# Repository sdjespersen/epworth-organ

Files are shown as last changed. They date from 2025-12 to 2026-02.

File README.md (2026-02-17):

# Epworth Organ

Encoders (`primary-encoder` being the primary), decoders (`primary-decoder` being the primary), etc. for the Epworth
organ, targeting the [Raspberry Pi Pico 2](https://datasheets.raspberrypi.com/pico/pico-2-datasheet.pdf), written in
Rust.

## Setup

The best dev setup for this involves using a
[Pico debug probe](https://www.raspberrypi.com/documentation/microcontrollers/debug-probe.html)
and [probe-rs](https://probe.rs). This allows you to get a SWD debugger and UART output, as well as flashing the program
to the chip without holding BOOTSEL while plugging in the USB. (Trust me, it gets old!)

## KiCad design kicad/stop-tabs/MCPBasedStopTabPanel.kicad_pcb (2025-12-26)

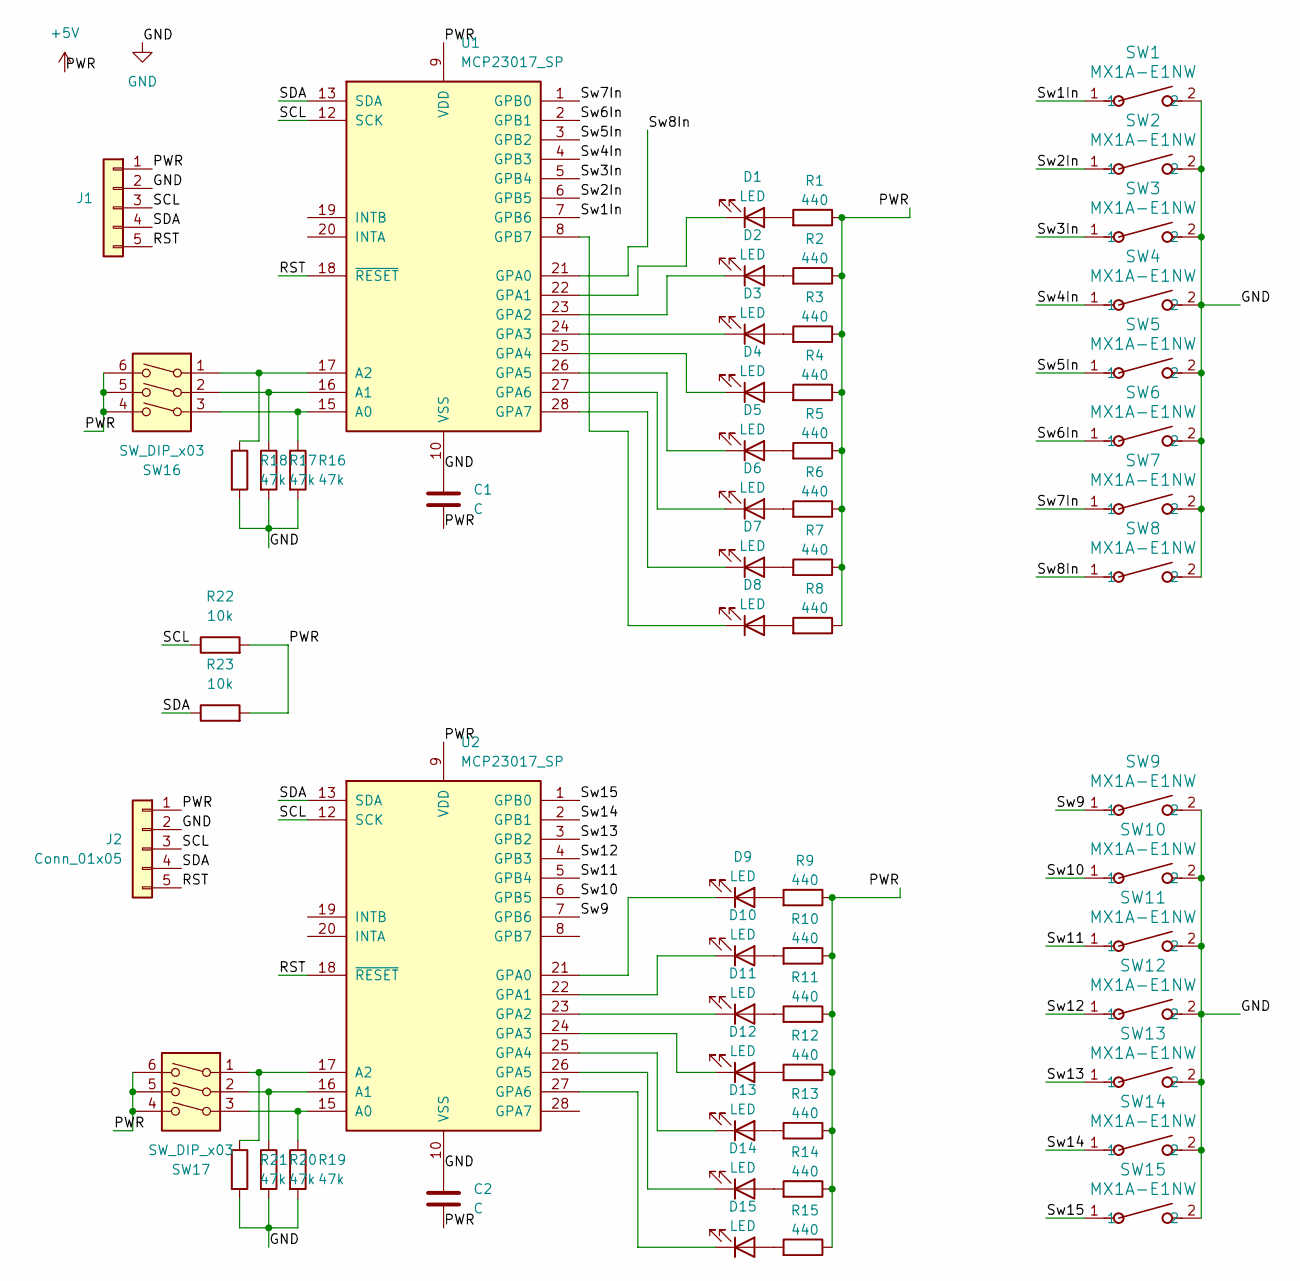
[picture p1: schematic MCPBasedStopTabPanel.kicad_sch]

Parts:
C1, C2: C; CAPRR508W50L508T317H508
D1, D2, D3, D4, D5, D6, D7, D8, D9, D10, D11, D12, D13, D14, D15: LED; LED_D5.0mm
J1, J2: Conn_01x05; JST_XH_B5B-XH-A_1x05_P2.50mm_Vertical
R1, R2, R3, R4, R5, R6, R7, R8, R9, R10, R11, R12, R13, R14, R15: 440; R_Axial_DIN0207_L6.3mm_D2.5mm_P7.62mm_Horizontal
R16, R17, R18, R19, R20, R21: 47k; R_Axial_DIN0207_L6.3mm_D2.5mm_P7.62mm_Horizontal
R22, R23: 10k; R_Axial_DIN0207_L6.3mm_D2.5mm_P7.62mm_Horizontal
SW1, SW2, SW3, SW4, SW5, SW6, SW7, SW8, SW9, SW10, SW11, SW12, SW13, SW14, SW15: MX1A-E1NW; SW_Cherry_MX_1.00u_PCB
SW16, SW17: SW_DIP_x03; SW_DIP_SPSTx03_Slide_9.78x9.8mm_W7.62mm_P2.54mm
U1, U2: MCP23017_SP; DIP-28_W7.62mm

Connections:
+5V: C1.2, C2.2, J1.1, J2.1, R1.1, R2.1, R3.1, R4.1, R5.1, R6.1, R7.1, R8.1, R9.1, R10.1, R11.1, R12.1, R13.1, R14.1, R15.1, R22.2, R23.2, SW16.4, SW16.5, SW16.6, SW17.4, SW17.5, SW17.6, U1.9 (VDD), U2.9 (VDD)
/RST: J1.5, J2.5, U1.18 (~RESET), U2.18 (~RESET)
/SCL: J1.3, J2.3, R22.1, U1.12 (SCK), U2.12 (SCK)
/SDA: J1.4, J2.4, R23.1, U1.13 (SDA), U2.13 (SDA)
/Sw1In: SW1.1, U1.7 (GPB6)
/Sw2In: SW2.1, U1.6 (GPB5)
/Sw3In: SW3.1, U1.5 (GPB4)
/Sw4In: SW4.1, U1.4 (GPB3)
/Sw5In: SW5.1, U1.3 (GPB2)
/Sw6In: SW6.1, U1.2 (GPB1)
/Sw7In: SW7.1, U1.1 (GPB0)
/Sw8In: SW8.1, U1.21 (GPA0)
/Sw9: SW9.1, U2.7 (GPB6)
/Sw10: SW10.1, U2.6 (GPB5)
/Sw11: SW11.1, U2.5 (GPB4)
/Sw12: SW12.1, U2.4 (GPB3)
/Sw13: SW13.1, U2.3 (GPB2)
/Sw14: SW14.1, U2.2 (GPB1)
/Sw15: SW15.1, U2.1 (GPB0)
GND: C1.1, C2.1, J1.2, J2.2, R16.2, R17.2, R18.2, R19.2, R20.2, R21.2, SW1.2, SW2.2, SW3.2, SW4.2, SW5.2, SW6.2, SW7.2, SW8.2, SW9.2, SW10.2, SW11.2, SW12.2, SW13.2, SW14.2, SW15.2, U1.10 (VSS), U2.10 (VSS)
unnamed: D1.2 (A), R1.2
unnamed: D1.1 (K), U1.22 (GPA1)
unnamed: D2.2 (A), R2.2
unnamed: D2.1 (K), U1.23 (GPA2)
unnamed: D3.2 (A), R3.2
unnamed: D3.1 (K), U1.24 (GPA3)
unnamed: D4.2 (A), R4.2
unnamed: D4.1 (K), U1.25 (GPA4)
unnamed: D5.2 (A), R5.2
unnamed: D5.1 (K), U1.26 (GPA5)
unnamed: D6.2 (A), R6.2
unnamed: D6.1 (K), U1.27 (GPA6)
unnamed: D7.2 (A), R7.2
unnamed: D7.1 (K), U1.28 (GPA7)
unnamed: D8.2 (A), R8.2
unnamed: D8.1 (K), U1.8 (GPB7)
unnamed: D9.2 (A), R9.2
unnamed: D9.1 (K), U2.21 (GPA0)
unnamed: D10.2 (A), R10.2
unnamed: D10.1 (K), U2.22 (GPA1)
unnamed: D11.2 (A), R11.2
unnamed: D11.1 (K), U2.23 (GPA2)
unnamed: D12.2 (A), R12.2
unnamed: D12.1 (K), U2.24 (GPA3)
unnamed: D13.2 (A), R13.2
unnamed: D13.1 (K), U2.25 (GPA4)
unnamed: D14.2 (A), R14.2
unnamed: D14.1 (K), U2.26 (GPA5)
unnamed: D15.2 (A), R15.2
unnamed: D15.1 (K), U2.27 (GPA6)
unnamed: R16.1, SW16.3, U1.15 (A0)
unnamed: R17.1, SW16.2, U1.16 (A1)
unnamed: R18.1, SW16.1, U1.17 (A2)
unnamed: R19.1, SW17.3, U2.15 (A0)
unnamed: R20.1, SW17.2, U2.16 (A1)
unnamed: R21.1, SW17.1, U2.17 (A2)

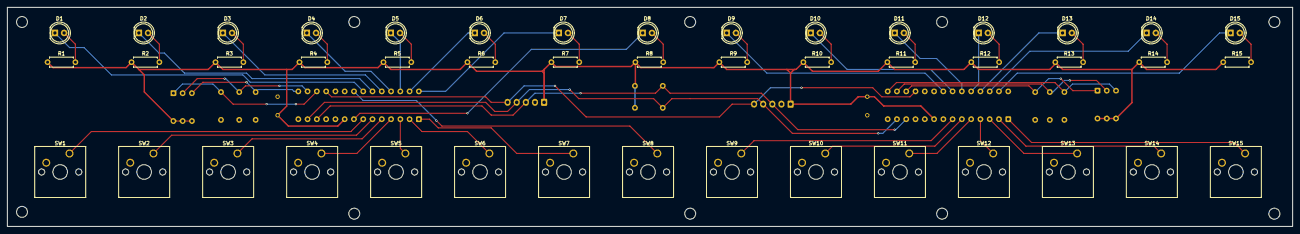
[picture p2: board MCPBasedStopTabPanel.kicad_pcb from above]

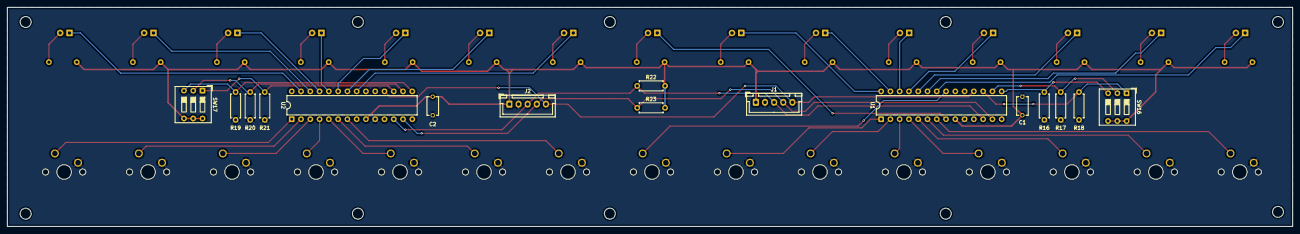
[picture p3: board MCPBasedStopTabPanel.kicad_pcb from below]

Board: 2 copper layers, 352.0 x 60.0 mm, 61 parts (16 on the bottom side), 56 nets.

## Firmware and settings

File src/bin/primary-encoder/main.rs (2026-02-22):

#![no_std]
#![no_main]

mod mcp23017;
mod presets;
mod usb_midi;

use panic_probe as _;

use core::cell::RefCell;

use embassy_embedded_hal::shared_bus::blocking::i2c::I2cDevice;
use embassy_executor::Spawner;
use embassy_rp::flash::Flash;
use embassy_rp::gpio::{AnyPin, Level, Output};
use embassy_rp::peripherals::{I2C0, SPI0, UART0, USB};
use embassy_rp::spi;
use embassy_rp::{Peri, bind_interrupts, i2c, uart, usb as rp_usb};
use embassy_sync::blocking_mutex::Mutex;
use embassy_sync::blocking_mutex::raw::CriticalSectionRawMutex;
use embassy_sync::channel::Channel;
use embassy_sync::signal::Signal;
use embassy_time::Timer;
use embassy_usb::class::midi as eusb_midi;
use embassy_usb::class::midi::MidiClass;
use embassy_usb::{Builder as UsbBuilder, Config as UsbConfig};
use embedded_io_async::Write;
use epworth_organ::Division;
use epworth_organ::command::{Command, CommandSource};
use epworth_organ::debouncer::Debouncer;
use epworth_organ::encoder::Encoder;
use epworth_organ::event::Event;
use epworth_organ::stops::{Stop, offset_to_div};
use epworth_organ::uart::UartReader;
use postcard::to_slice_cobs;
use static_cell::{ConstStaticCell, StaticCell};

use crate::mcp23017::MCP23017;
use crate::mcp23017::Port;
use crate::presets::Presets;
use crate::usb_midi::{receive_command_from_usb, write_event_to_usb};

type I2c0Bus = Mutex<CriticalSectionRawMutex, RefCell<i2c::I2c<'static, I2C0, i2c::Blocking>>>;
type I2c0Mcp =
    MCP23017<I2cDevice<'static, CriticalSectionRawMutex, i2c::I2c<'static, I2C0, i2c::Blocking>>>;

bind_interrupts!(struct Irqs {
    USBCTRL_IRQ => rp_usb::InterruptHandler<USB>;
    UART0_IRQ => uart::BufferedInterruptHandler<UART0>;
});

// These two indices have to be determined when everything is hooked up.
const SAVE_PISTON_IDX: u8 = 7;
const GENERAL_CANCEL_PISTON_IDX: u8 = 6;
const MCP_I2C_ADDRESSES: [[u8; 2]; 4] = [[0x20, 0x21], [0x22, 0x23], [0x24, 0x25], [0x26, 0x27]];
const DIVISIONS: [Division; 4] = [
    Division::Swell,
    Division::Great,
    Division::Choir,
    Division::Pedal,
];

// This stop state representation is LSB first, i.e. looking at the stop tab panels from the front, LSB is on the left.
// Furthermore, the 16 bits corresponding to the swell division are in the 16 lowest bits, the next 16 are the great,
// followed by the choir division and finally the pedal division. The MSB for each division is always 0, as it is not
// connected to any physical hardware. (No division has more than 15 stops.)
static STOP_STATE: Signal<CriticalSectionRawMutex, u64> = Signal::new();
static PRESET_STORE: StaticCell<Presets> = StaticCell::new();

// Queue for all commands on the organ. These commands can be either generated by mechanical interactions with the
// console (e.g. pressing a stop tab button, moving an expression pedal, etc.), including mechanical interactions
// relayed to this particular MCU over UART, or they can be received over USB MIDI.
static COMMANDS: Channel<CriticalSectionRawMutex, (Command, CommandSource), 8> = Channel::new();

// Queues for events destined for the decoders (via UART) or the computer (via USB).
static UART_EVENTS: Channel<CriticalSectionRawMutex, Event, 8> = Channel::new();
static USB_EVENTS: Channel<CriticalSectionRawMutex, Event, 8> = Channel::new();

static USB_CONFIG_DESCRIPTOR: ConstStaticCell<[u8; 512]> = ConstStaticCell::new([0; 512]);
static USB_BOS_DESCRIPTOR: ConstStaticCell<[u8; 256]> = ConstStaticCell::new([0; 256]);
static USB_CONTROL_BUF: ConstStaticCell<[u8; 128]> = ConstStaticCell::new([0; 128]);

fn get_mcps(i2c_bus: &'static I2c0Bus) -> [[I2c0Mcp; 2]; 4] {
    MCP_I2C_ADDRESSES.map(|[addr0, addr1]| {
        [
            MCP23017::new(I2cDevice::new(i2c_bus), addr0),
            MCP23017::new(I2cDevice::new(i2c_bus), addr1),
        ]
    })
}

#[embassy_executor::task]
async fn write_stop_state_to_leds(i2c_bus: &'static I2c0Bus) {
    let mcp_pairs = &mut get_mcps(i2c_bus);

    loop {
        let mut stop_state: u64 = STOP_STATE.wait().await;

        // This is our approach to batching lots of little changes: Wait for a brief interval before reading the stop
        // states again.
        Timer::after_millis(1).await;

        stop_state = STOP_STATE.try_take().unwrap_or(stop_state);

        for (mcp_pair, div) in mcp_pairs.iter_mut().zip(DIVISIONS) {
            // Remember, stop state is LSB first.
            let state = stop_state >> (16 * div as u8) & 0xFFFF;
            let left_half = !(state & 0xFF) as u8;
            let right_half = !(state >> 8) as u8;
            mcp_pair[0]
                .write_gpio(Port::GPIOA, (left_half & 0x7F) << 1)
                .unwrap();
            mcp_pair[0]
                .write_gpio(Port::GPIOB, left_half & 0x80)
                .unwrap();
            mcp_pair[1]
                .write_gpio(Port::GPIOA, right_half & 0x7F)
                .unwrap();
        }
    }
}

#[embassy_executor::task]
async fn scan_stop_tab_buttons(i2c_bus: &'static I2c0Bus) {
    let mut mcp_pairs = get_mcps(i2c_bus);
    let mut stop_tab_button_debouncer: Debouncer<5> = Debouncer::<5>::new(!0u64);

    loop {
        let mut raw_reading = 0u64;
        for (j, mcp_pair) in mcp_pairs.iter_mut().enumerate() {
            // These readings are L-to-R looking at the front of the stop tab panels, aka MSB first.
            let mut raw_div_reading = 0x01u16; // LSB always 1, not hooked up
            raw_div_reading |= ((mcp_pair[0].read_gpio(Port::GPIOA).unwrap() & 0x01) as u16) << 8;
            raw_div_reading |= ((mcp_pair[0].read_gpio(Port::GPIOB).unwrap() & 0x7F) as u16) << 9;
            raw_div_reading |= ((mcp_pair[1].read_gpio(Port::GPIOB).unwrap() & 0x7F) as u16) << 1;
            raw_reading |= (raw_div_reading as u64) << (16 * j);
        }
        stop_tab_button_debouncer.update(raw_reading);
        for i in stop_tab_button_debouncer.falling_edges() {
            // Because the raw readings (and hence debouncers) are MSB first, need to invert the stop number.
            if let Some(stop) = Stop::try_from(offset_to_div(i), 15 - (i % 16)) {
                COMMANDS
                    .send((Command::StopToggle(stop), CommandSource::Local))
                    .await;
            }
        }
        Timer::after_micros(500).await;
    }
}

#[embassy_executor::task]
async fn scan_pistons(
    mut spi: spi::Spi<'static, SPI0, spi::Async>,
    load_pin: Peri<'static, AnyPin>,
) {
    let mut piston_debouncer = Debouncer::<5>::new(!0u64);

    let mut piston_load_pin = Output::new(load_pin, Level::Low);

    loop {
        // Load piston states into 74HC165 shift registers
        piston_load_pin.set_low();
        piston_load_pin.set_high();

        let mut rx_buf = [0u8; 4];
        let _ = spi.read(&mut rx_buf).await;

        let raw_piston_reading = rx_buf[0] as u64
            | ((rx_buf[1] as u64) << 8)
            | ((rx_buf[2] as u64) << 16)
            | ((rx_buf[3] as u64) << 24);

        piston_debouncer.update(raw_piston_reading);

        for i in piston_debouncer.falling_edges() {
            if i == SAVE_PISTON_IDX {
                COMMANDS
                    .send((Command::EnableSave(true), CommandSource::Local))
                    .await;
            } else if i == GENERAL_CANCEL_PISTON_IDX {
                COMMANDS
                    .send((Command::GeneralCancel(), CommandSource::Local))
                    .await;
            } else {
                COMMANDS
                    .send((Command::RecallPreset(i), CommandSource::Local))
                    .await;
            }
        }

        for i in piston_debouncer.rising_edges() {
            if i == SAVE_PISTON_IDX {
                COMMANDS
                    .send((Command::EnableSave(false), CommandSource::Local))
                    .await;
            }
        }

        Timer::after_micros(500).await;
    }
}

#[embassy_executor::task]
async fn usb_midi_writer(
    mut usb_midi_tx: eusb_midi::Sender<'static, rp_usb::Driver<'static, USB>>,
) {
    // TODO: Handle the case where the USB cable gets connected/disconnected while the program is running.
    // We can probably implement this by breaking out of the inner loop if we time out when writing packets.
    usb_midi_tx.wait_connection().await;

    loop {
        let event = USB_EVENTS.receive().await;
        write_event_to_usb(event, &mut usb_midi_tx).await;
    }
}

#[embassy_executor::task]
async fn usb_midi_reader(
    mut usb_midi_rx: eusb_midi::Receiver<'static, rp_usb::Driver<'static, USB>>,
) {
    // TODO: Handle the case where the USB cable gets connected/disconnected while the program is running.
    usb_midi_rx.wait_connection().await;

    let mut data = [0u8; 64];

    loop {
        receive_command_from_usb(&mut data, &mut usb_midi_rx, async |cmd| {
            COMMANDS.send((cmd, CommandSource::External)).await;
        })
        .await;
    }
}

#[embassy_executor::task]
async fn usb_midi(spawner: Spawner, usb: Peri<'static, USB>) {
    let driver = rp_usb::Driver::new(usb, Irqs);
    let mut config = UsbConfig::new(0xc0de, 0xcafe);
    config.manufacturer = Some("RP Pico 2");
    config.product = Some("Epworth Organ MIDI");
    config.serial_number = Some("12345678");
    config.max_power = 100;
    config.max_packet_size_0 = 64;

    let mut builder = UsbBuilder::new(
        driver,
        config,
        USB_CONFIG_DESCRIPTOR.take(),
        USB_BOS_DESCRIPTOR.take(),
        &mut [], // no msos descriptors
        USB_CONTROL_BUF.take(),
    );

    let midi_class = MidiClass::new(&mut builder, 1, 1, 64);

    // Build the builder.
    let mut usb_device = builder.build();

    let (usb_midi_tx, usb_midi_rx) = midi_class.split();

    spawner.spawn(usb_midi_writer(usb_midi_tx)).unwrap();
    spawner.spawn(usb_midi_reader(usb_midi_rx)).unwrap();

    // Run the USB device forever.
    loop {
        usb_device.run().await;
    }
}

#[embassy_executor::task]
async fn uart_reader(uart_rx: uart::BufferedUartRx) {
    let mut uart_rdr = UartReader::new(uart_rx);

    loop {
        uart_rdr
            .feed::<Command>(async |data| {
                COMMANDS.send((data, CommandSource::Local)).await;
            })
            .await;
    }
}

#[embassy_executor::task]
async fn uart_writer(mut uart_tx: uart::BufferedUartTx) {
    loop {
        let event = UART_EVENTS.receive().await;
        // We have to be careful here about buffer size! Preset recall serializes to 12 bytes in my testing. I'm
        // leaving a few extra just in case i introduce anything around that size.
        let mut buf = [0u8; 16];
        let written = to_slice_cobs(&event, &mut buf).unwrap();
        let _ = uart_tx.write_all(written).await;
    }
}

fn setup_mcps(i2c_bus: &'static I2c0Bus) {
    for mcp_pair in get_mcps(i2c_bus).iter_mut() {
        mcp_pair[0].init_hardware().unwrap();
        mcp_pair[1].init_hardware().unwrap();
        // Set pin modes (input/output) for MCP23017s based on the schematic
        mcp_pair[0].port_mode(Port::GPIOA, 0x01).unwrap();
        mcp_pair[0].port_mode(Port::GPIOB, 0x7F).unwrap();
        mcp_pair[1].port_mode(Port::GPIOA, 0x00).unwrap();
        mcp_pair[1].port_mode(Port::GPIOB, 0x7F).unwrap();
        // Write all outputs high, inputs low.
        mcp_pair[0].write_gpio(Port::GPIOA, 0xFE).unwrap();
        mcp_pair[0].write_gpio(Port::GPIOB, 0x80).unwrap();
        mcp_pair[1].write_gpio(Port::GPIOA, 0x7F).unwrap();
        mcp_pair[1].write_gpio(Port::GPIOB, 0x00).unwrap();
    }
}

#[embassy_executor::task]
async fn main_event_handler(preset_store: &'static mut Presets<'static>) {
    // let mut stop_state: u64 = 0u64;
    // let mut awaiting_save = false;
    let mut encoder = Encoder::new(preset_store);

    // Flush initial stop state.
    STOP_STATE.signal(encoder.get_stop_state());

    loop {
        let (command, src) = COMMANDS.receive().await;

        let command_result = encoder.handle(command).await;

        if command_result.1 {
            STOP_STATE.signal(encoder.get_stop_state())
        }

        if let Some(e) = command_result.0 {
            if let CommandSource::Local = src {
                let _ = USB_EVENTS.try_send(e);
            }
            UART_EVENTS.send(e).await;
        }
    }
}

#[embassy_executor::main]
async fn main(spawner: Spawner) {
    let p = embassy_rp::init(Default::default());

    let i2c = embassy_rp::i2c::I2c::new_blocking(p.I2C0, p.PIN_5, p.PIN_4, i2c::Config::default());
    static I2C_BUS: StaticCell<I2c0Bus> = StaticCell::new();
    let i2c_bus = I2C_BUS.init(Mutex::new(i2c.into()));

    let spi = spi::Spi::new_rxonly(
        p.SPI0,
        p.PIN_18,
        p.PIN_16,
        p.DMA_CH1,
        p.DMA_CH2,
        spi::Config::default(),
    );
    spawner.spawn(scan_pistons(spi, p.PIN_17.into())).unwrap();

    spawner
        .spawn(main_event_handler(
            PRESET_STORE.init(Presets::new(Flash::new(p.FLASH, p.DMA_CH0))),
        ))
        .unwrap();

    static TX_BUF: StaticCell<[u8; 16]> = StaticCell::new();
    let tx_buf = &mut TX_BUF.init([0; 16])[..];
    static RX_BUF: StaticCell<[u8; 16]> = StaticCell::new();
    let rx_buf = &mut RX_BUF.init([0; 16])[..];
    let uart_txrx = uart::BufferedUart::new(
        p.UART0,
        p.PIN_0,
        p.PIN_1,
        Irqs,
        tx_buf,
        rx_buf,
        uart::Config::default(),
    );
    let (uart_tx, uart_rx) = uart_txrx.split();
    spawner.spawn(uart_reader(uart_rx)).unwrap();
    spawner.spawn(uart_writer(uart_tx)).unwrap();

    setup_mcps(i2c_bus);
    spawner.spawn(scan_stop_tab_buttons(i2c_bus)).unwrap();
    spawner.spawn(write_stop_state_to_leds(i2c_bus)).unwrap();
    spawner.spawn(usb_midi(spawner, p.USB)).unwrap();

    defmt::info!("All tasks spawned.");

    // Heartbeat task comes last, and happens on the main loop, roughly indicating that all tasks spawned successfully.
    let mut led = Output::new(p.PIN_25, Level::Low);

    loop {
        led.toggle();
        Timer::after_secs(1).await;
    }
}

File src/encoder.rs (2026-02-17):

use crate::{command::Command, event::Event};

pub trait PresetStore {
    fn save(&mut self, key: u8, value: u64) -> impl Future<Output = ()>;
    fn load(&mut self, key: u8) -> impl Future<Output = u64>;
}

pub struct Encoder<'d, T: PresetStore> {
    stops: u64,
    awaiting_save: bool,
    preset_store: &'d mut T,
}

pub struct CommandResult(pub Option<Event>, pub bool);

impl<'d, T: PresetStore> Encoder<'d, T> {
    pub fn new(preset_store: &'d mut T) -> Self {
        Self {
            stops: 0u64,
            awaiting_save: false,
            preset_store: preset_store,
        }
    }

    pub fn get_stop_state(&self) -> u64 {
        self.stops
    }

    // This is the guts of the primary encoder MCU. All commands issued to the organ go through this handler in order
    // to affect any state on the organ. Some commands pass through essentially untouched to the decoder, while others
    // may be "absorbed" by the encoder and result in zero outbound events (e.g. "save preset"). This handler applies
    // state-related logic to incoming encoder commands (e.g. "toggle" messages converted to "on" or "off" depending on
    // state), but it does not concern itself with couplings; those will be handled by the decoder.
    pub async fn handle(&mut self, cmd: Command) -> CommandResult {
        match cmd {
            Command::NoteOff(div, value) => CommandResult(Some(Event::NoteOff(div, value)), false),
            Command::NoteOn(div, value) => CommandResult(Some(Event::NoteOn(div, value)), false),
            Command::StopOff(stop) => {
                self.stops &= !(1 << stop.offset());
                CommandResult(Some(Event::StopOff(stop)), true)
            }
            Command::StopOn(stop) => {
                self.stops |= 1 << stop.offset();
                CommandResult(Some(Event::StopOn(stop)), true)
            }
            Command::StopToggle(stop) => {
                let mask = 1 << stop.offset();
                self.stops ^= mask;
                if self.stops & mask != 0 {
                    CommandResult(Some(Event::StopOn(stop)), true)
                } else {
                    CommandResult(Some(Event::StopOff(stop)), true)
                }
            }
            Command::GeneralCancel() => {
                self.stops = 0;
                CommandResult(Some(Event::GeneralCancel()), true)
            }
            Command::RecallPreset(idx) => {
                if self.awaiting_save {
                    // Saving a preset is internal; it emits no events.
                    self.preset_store.save(idx, self.stops).await;
                    // Safety: Disengage save mode if we've already written a preset.
                    self.awaiting_save = false;
                    CommandResult(None, false)
                } else {
                    self.stops = self.preset_store.load(idx).await;
                    CommandResult(Some(Event::PresetRecalled(idx, self.stops)), true)
                }
            }
            Command::EnableSave(val) => {
                self.awaiting_save = val;
                CommandResult(None, false)
            }
            Command::Expression(div, value) => {
                CommandResult(Some(Event::Expression(div, value)), false)
            }
            Command::Crescendo(value) => CommandResult(Some(Event::Crescendo(value)), false),
        }
    }
}

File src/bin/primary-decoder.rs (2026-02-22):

#![no_std]
#![no_main]

use embassy_sync::signal::Signal;
use panic_probe as _;

use embassy_executor::Spawner;
use embassy_rp::gpio::{AnyPin, Level, Output};
use embassy_rp::peripherals::{SPI0, UART0};
use embassy_rp::spi;
use embassy_rp::{Peri, bind_interrupts, uart};
use embassy_sync::blocking_mutex::raw::CriticalSectionRawMutex;
use embassy_sync::channel::Channel;
use embassy_time::Timer;
use epworth_organ::decoder::Decoder;
use epworth_organ::event::Event;
use epworth_organ::uart::UartReader;
use static_cell::StaticCell;

bind_interrupts!(struct Irqs {
    UART0_IRQ => uart::BufferedInterruptHandler<UART0>;
});

const B: [u32; 4] = [0x55555555, 0x33333333, 0x0F0F0F0F, 0x00FF00FF];
const S: [u32; 4] = [1, 2, 4, 8];
const NIBBLE_REVERSE_LOOKUP: [u8; 16] = [
    0x0, 0x8, 0x4, 0xc, 0x2, 0xa, 0x6, 0xe, 0x1, 0x9, 0x5, 0xd, 0x3, 0xb, 0x7, 0xf,
];

// Queue for all events on the decoder. The only way events make it onto the decoder is over UART.
static EVENTS: Channel<CriticalSectionRawMutex, Event, 8> = Channel::new();
static STOP_STATE: Signal<CriticalSectionRawMutex, u64> = Signal::new();

fn interleave_bits(mut x: u32, mut y: u32) -> u32 {
    for i in (0..4).rev() {
        x = (x | (x << S[i])) & B[i];
        y = (y | (y << S[i])) & B[i];
    }
    x | (y << 1)
}

#[embassy_executor::task]
async fn write_stop_state(
    mut spi: spi::Spi<'static, SPI0, spi::Async>,
    latch_pin: Peri<'static, AnyPin>,
) {
    let mut stops_latch_pin = Output::new(latch_pin, Level::Low);

    loop {
        let mut stop_state: u64 = STOP_STATE.wait().await;

        // This is our approach to batching lots of little changes: Wait for a brief interval before reading the stop
        // states again.
        Timer::after_millis(1).await;

        stop_state = STOP_STATE.try_take().unwrap_or(stop_state);

        // There's a lot going on the in the next few paragraphs.
        //
        // First off, the stop state saved in this program is ordered logically in terms of manuals: swell, great,
        // choir, and finally pedal. However, the way the stops are electrically wired in the combination action box is
        // completely different. From organist's left to right, it goes swell, pedal, swell, pedal, ... until the swell
        // and pedal stops are exhausted, and then it picks up with great, choir, great, choir, etc. This means that
        // we need to "interleave" the bits of the swell stop state with the bits of the pedal stop state, and same for
        // the great and the choir.
        //
        // Second, the wiring of the outputs on the MIC5891YN line drivers necessitates a further reshuffling. Because
        // of the pinout on the chip, we need to remap the bit positions in each byte as follows:
        // 0 -> 4, 1 -> 5, 2 -> 6, 3 -> 7, 4 -> 3, 5 -> 2, 6 -> 1, 7 -> 0
        // Reversing the high nibble and then swapping high and low nibbles accomplishes this.
        let left_half = interleave_bits(
            (stop_state >> 16 & 0xFFFF) as u32,
            (stop_state >> 32 & 0xFFFF) as u32,
        );
        let right_half = interleave_bits(
            (stop_state >> 48 & 0xFFFF) as u32,
            (stop_state & 0xFFFF) as u32,
        );

        let mut buf: [u8; 8] = ((left_half as u64) << 32 | (right_half as u64)).to_le_bytes();
        for i in 0..buf.len() {
            // Reverse high nibble, then swap nibbles
            buf[i] =
                ((buf[i] & 0x0F) << 4) | NIBBLE_REVERSE_LOOKUP[((buf[i] & 0xF0) >> 4) as usize];
        }
        let _ = spi.write(&buf).await;

        stops_latch_pin.set_high();
        stops_latch_pin.set_low();
    }
}

#[embassy_executor::task]
async fn uart_reader(uart_rx: uart::BufferedUartRx) {
    let mut uart_rdr = UartReader::new(uart_rx);

    loop {
        uart_rdr
            .feed::<Event>(async |event| {
                EVENTS.send(event).await;
            })
            .await;
    }
}

#[embassy_executor::task]
async fn main_event_handler() {
    let mut decoder = Decoder::new();

    // Signal the initial stop state.
    STOP_STATE.signal(decoder.stop_state());

    loop {
        let event = EVENTS.receive().await;
        let result = decoder.handle(event);
        if let Some(stop_state) = result.stop_state {
            STOP_STATE.signal(stop_state);
        }
    }
}

#[embassy_executor::main]
async fn main(spawner: Spawner) {
    let p = embassy_rp::init(Default::default());

    // Disable stops output until writer task is ready.
    let mut stops_oe_pin = Output::new(p.PIN_21, Level::High);

    spawner.spawn(main_event_handler()).unwrap();

    static TX_BUF: StaticCell<[u8; 16]> = StaticCell::new();
    let tx_buf = &mut TX_BUF.init([0; 16])[..];
    static RX_BUF: StaticCell<[u8; 16]> = StaticCell::new();
    let rx_buf = &mut RX_BUF.init([0; 16])[..];
    let uart_txrx = uart::BufferedUart::new(
        p.UART0,
        p.PIN_0,
        p.PIN_1,
        Irqs,
        tx_buf,
        rx_buf,
        uart::Config::default(),
    );
    let (_uart_tx, uart_rx) = uart_txrx.split();
    spawner.spawn(uart_reader(uart_rx)).unwrap();
    // spawner.spawn(uart_writer(uart_tx)).unwrap();

    let spi = spi::Spi::new_txonly(
        p.SPI0,
        p.PIN_18,
        p.PIN_19,
        p.DMA_CH0,
        spi::Config::default(),
    );
    spawner
        .spawn(write_stop_state(spi, p.PIN_20.into()))
        .unwrap();
    // Enable stops output now that the writer task is ready.
    stops_oe_pin.set_low();

    // Heartbeat task comes last, and happens on the main loop, roughly indicating that all tasks spawned successfully.
    let mut led = Output::new(p.PIN_25, Level::Low);

    loop {
        led.toggle();
        Timer::after_secs(1).await;
    }
}

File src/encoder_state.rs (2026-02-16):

use crate::presets::PresetStore;
use crate::{command::Command, event::Event};

pub struct EncoderState<'d> {
    stop_state: u64,
    awaiting_save: bool,
    preset_store: &'d mut PresetStore<'d>,
}

pub struct CommandResult(pub Option<Event>, pub bool);

impl<'d> EncoderState<'d> {
    pub fn new(preset_store: &'d mut PresetStore<'d>) -> Self {
        Self {
            stop_state: 0u64,
            awaiting_save: false,
            preset_store: preset_store,
        }
    }

    pub fn get_stop_state(&self) -> u64 {
        self.stop_state
    }

    pub async fn command(&mut self, cmd: Command) -> CommandResult {
        // This is the guts of the primary encoder MCU. All commands issued to the organ go through this event loop in
        // order to affect any state on the organ. Some commands pass through essentially untouched to the decoder,
        // while others may result in numerous or even zero outbound events. This first match applies state-related
        // logic to incoming encoder commands (e.g. "toggle" messages converted to "on" or "off" depending on state).
        match cmd {
            Command::NoteOff(div, value) => CommandResult(Some(Event::NoteOff(div, value)), false),
            Command::NoteOn(div, value) => CommandResult(Some(Event::NoteOn(div, value)), false),
            Command::StopOff(div, idx) => {
                self.stop_state &= !(1 << 16 * div as u8 + idx);
                CommandResult(Some(Event::StopOff(div, idx)), true)
            }
            Command::StopOn(div, idx) => {
                self.stop_state |= 1 << 16 * div as u8 + idx;
                CommandResult(Some(Event::StopOn(div, idx)), true)
            }
            Command::StopToggle(div, idx) => {
                let shift = 16 * div as u8 + idx;
                self.stop_state ^= 1 << shift;
                if self.stop_state >> shift & 1 == 1 {
                    CommandResult(Some(Event::StopOn(div, idx)), true)
                } else {
                    CommandResult(Some(Event::StopOff(div, idx)), true)
                }
            }
            Command::GeneralCancel() => {
                self.stop_state = 0;
                CommandResult(Some(Event::GeneralCancel()), true)
            }
            Command::RecallPreset(idx) => {
                if self.awaiting_save {
                    // Saving a preset is internal; it emits no events.
                    self.preset_store.save(idx, &self.stop_state).await;
                    // Safety: Disengage save mode if we've already written one preset.
                    self.awaiting_save = false;
                    CommandResult(None, false)
                } else {
                    self.stop_state = self.preset_store.load(idx).await;
                    CommandResult(Some(Event::PresetRecalled(idx, self.stop_state)), true)
                }
            }
            Command::EnableSave(val) => {
                self.awaiting_save = val;
                CommandResult(None, false)
            }
            Command::Expression(div, value) => {
                CommandResult(Some(Event::Expression(div, value)), false)
            }
            Command::Crescendo(value) => CommandResult(Some(Event::Crescendo(value)), false),
        }
    }
}

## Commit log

2025-12-15 Fake encoder for testing
2025-12-24 Draft of stop tab buttons
2025-12-26 Add KiCad project/schematic/PCB design for stop tab panel.
    [MCPBasedStopTabPanel.kicad_pcb, MCPBasedStopTabPanel.kicad_sch]
2026-01-01 Button presses are detectable now!
2026-01-01 Ignore some KiCad artifacts
2026-01-02 Encoder and decoder working on Teensy!
    Tested it out, and the Teensys talk to each other just fine over a
    single line ("unidirectional UART"?). I tried to get this working
    with an Arduino Nano Every playing the role of encoder, but had
    trouble transmitting MIDI data properly.
2026-01-02 Encoder code works on Arduino Nano Every!
2026-01-02 Pistons functional!
2026-01-07 Fix bug with LED D9.
2026-01-14 Encoder is now in Rust.
2026-01-14 Aaaand decoder ported to Rust, too.
    There was a small bugfix in the encoder.
    [main.rs]
2026-01-14 Add heartbeat LED and small loop delay.
2026-02-12 Feature/rp2350 (#1)
    * First draft of RP2350. Going well!
    Uses Embassy, async, all the bells and whistles.
    * Make heartbeat the "main" task
    * Add lil note about stop state flushing
    * Batch LED changes
    * Add first bits of USB MIDI functionality.
    CC only for now.
    I think i have an issue during preset recall: In fact, i should emit
    all corresponding MIDI CCs, but right now it does not do that.
    * Set a timeout on USB writes.
    This solves the issue wherein we block forever because nobody is
    "listening" on the USB port.
    * Make usb config-related static cells `ConstStaticCell`.
    * Preset recall now emits MIDI CCs.
    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
    [main.rs, mcp23017.rs]
2026-02-12 Use same reading logic for UART
2026-02-16 Break out encoder and decoder state (pure logic)
2026-02-16 Invert dependency on preset store impl
    [encoder.rs, main.rs]
2026-02-17 Factor out common UART reading logic
2026-02-18 Scan pistons with SPI!
2026-02-18 Remove crescendo from primary encoder.
    It will live on a separate Pico. It was there just for testing.
2026-02-18 Change board layout.
2026-02-20 Move stop state writing to SPI bus
2026-02-21 Move UART0 to presumably final location.
2026-02-22 Fix a bug in saving presets and use first 16 switches.
    TODO: Remaining 16 switches.
    [main.rs]
2026-02-22 Debouncer now u64-based. Pistons should work.
